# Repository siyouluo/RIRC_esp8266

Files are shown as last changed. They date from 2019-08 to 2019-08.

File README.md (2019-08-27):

# RIRC 红外遥控器

# 产品说明
本产品是一个空调遥控器，可以通过移动端APP进行远程控制。其硬件底层是通过模拟原装空调遥控器的红外波形，从而实现对特定型号空调的控制(暂仅支持格力空调YB0F2型号遥控器)。  
使用时需要将本产品连接到WiFi网络，手机需要安装对应APP并连网(数据网络或者WiFi)，手机**无需**和本产品处于同一局域网环境。  

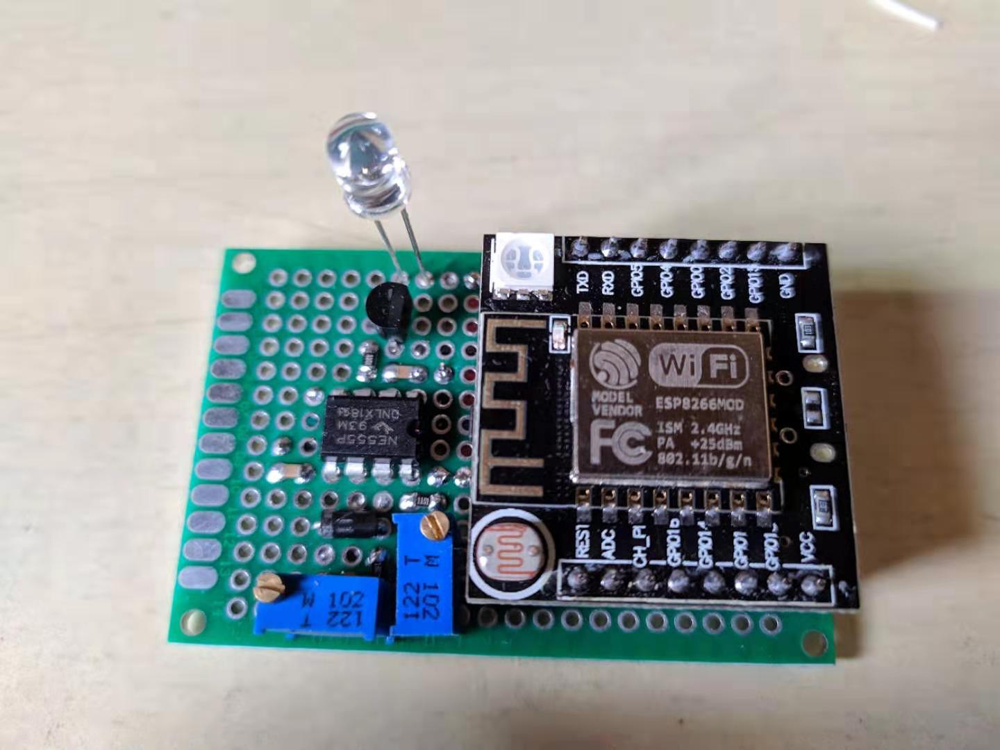
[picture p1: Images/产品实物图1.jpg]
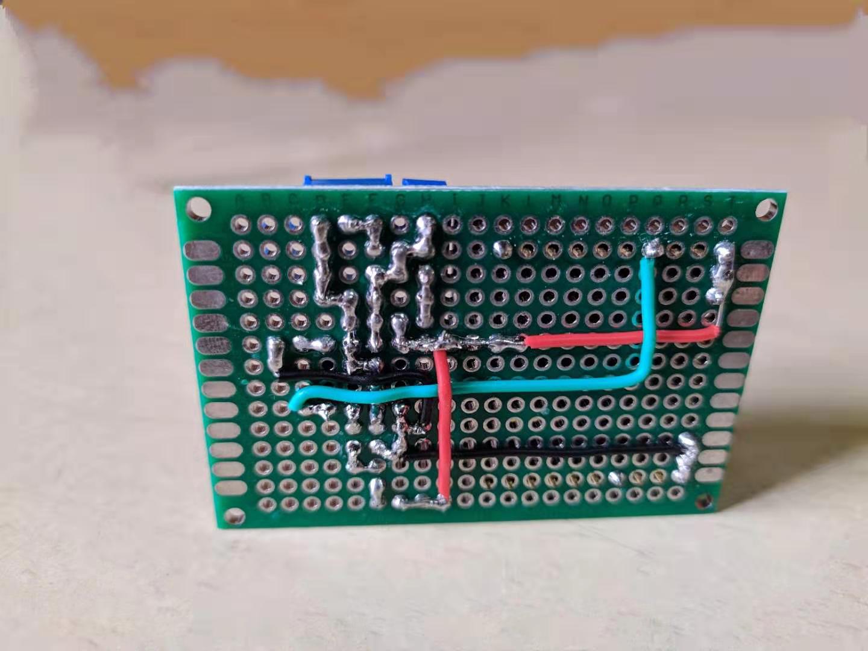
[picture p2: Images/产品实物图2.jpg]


本产品的主要使用场景有： 

1. 手机本身不包含红外发射装置，但又希望能直接通过手机控制空调;
2. 希望在户外提前打开空调，待用户到达房间时，温度已经调节合适;
3. 使用传感器获取当前时间、房间温度、光照强度等参数，并通过软件实现自动控制(暂未实现).

# 开发环境/辅助软件
Windows10 + VirtualBox虚拟机(lubuntu)

Multisim12.0 + Fritzing0.9.0b

# 器件清单
|元件|功能|图片|补充说明|参考价格|
|:---|:---|:---:|:---|:---|
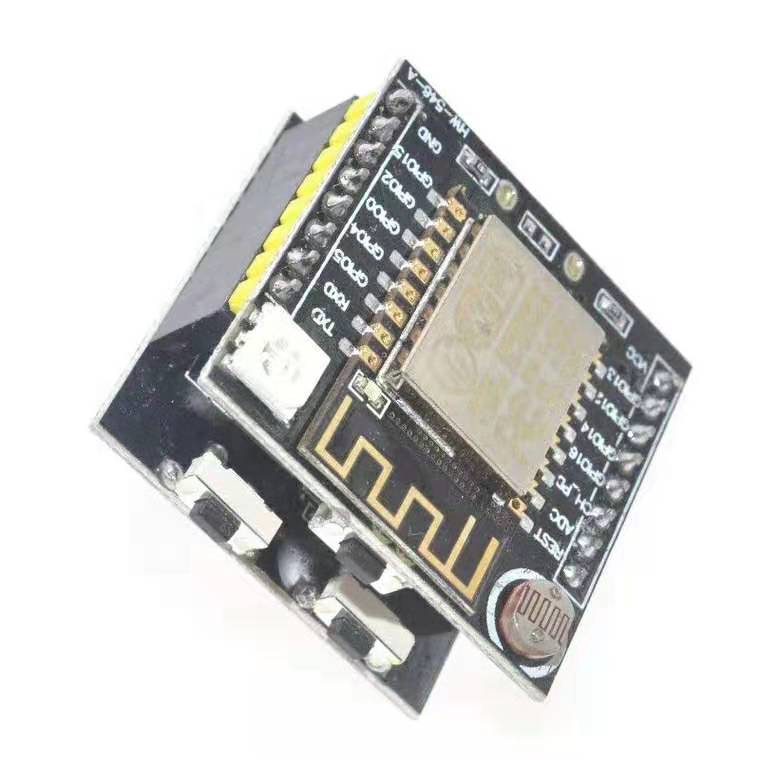
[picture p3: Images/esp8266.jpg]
|ESP8266-12F|WiFi模块||俗称“小黑板”|&yen;30.96| 
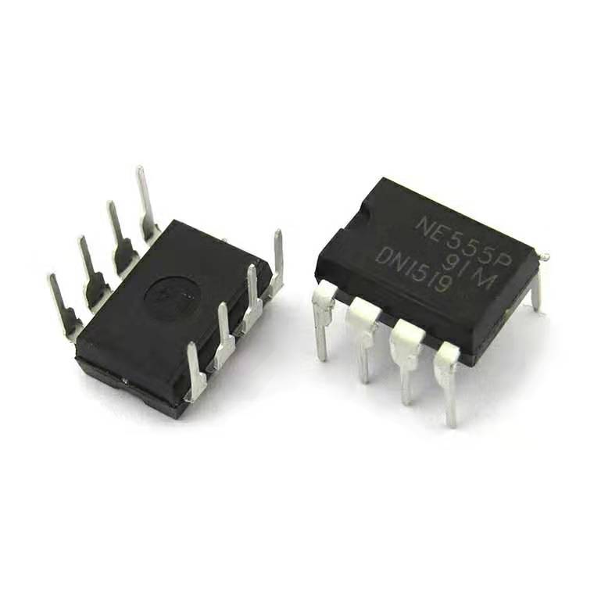
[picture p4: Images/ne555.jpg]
|NE555|定时器||DIP-8封装|&yen;3.6/10个|
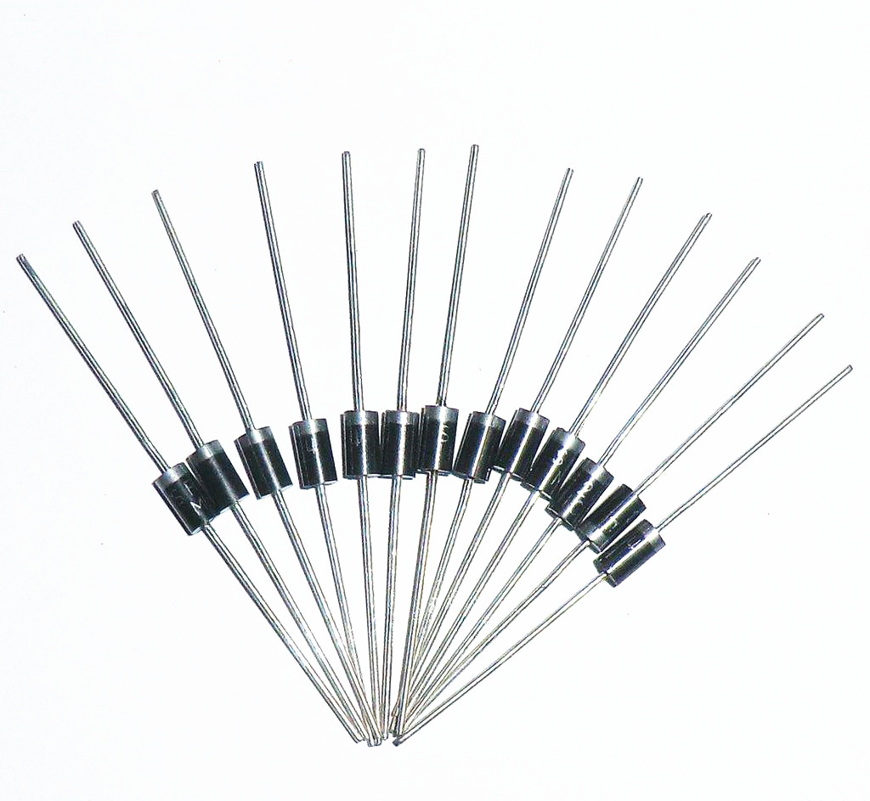
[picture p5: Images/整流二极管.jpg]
|整流二极管|振荡器辅助元件||便于调节占空比|&yen;5.5/100只|
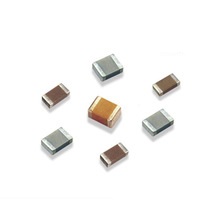
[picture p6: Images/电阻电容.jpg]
|电阻、电容|振荡器辅助元件||0805贴片封装|&yen;3.7/100个|  
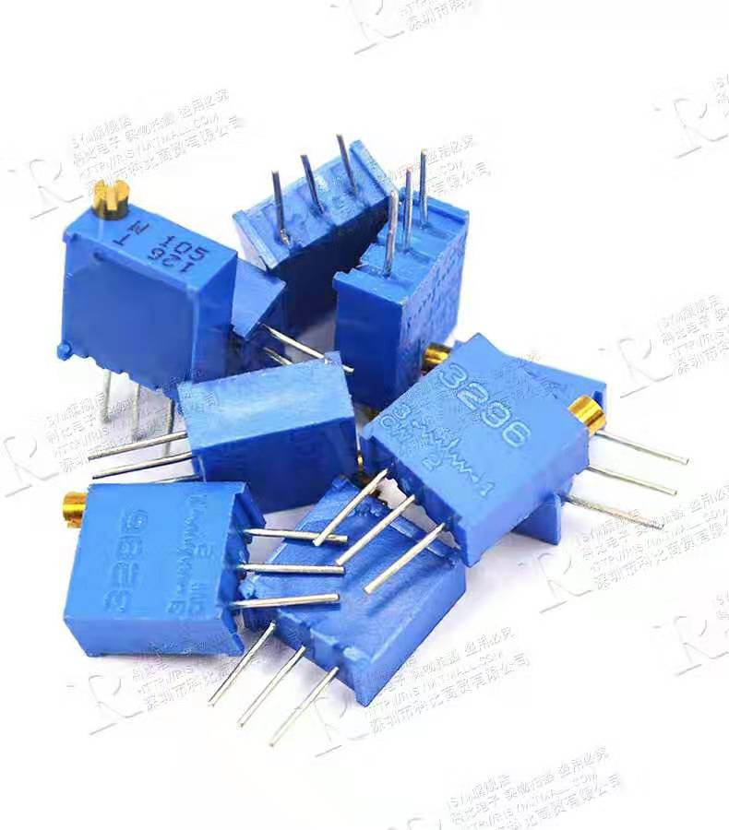
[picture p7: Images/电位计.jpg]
|多圈可调精密电位计|调节载波频率和占空比||3296W封装|&yen;2.31/5个|  
|NPN三极管|基本共射放大||9013|&yen;2.36/50个|  
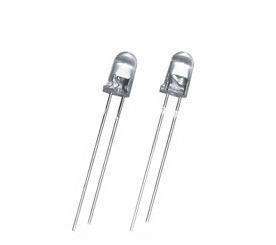
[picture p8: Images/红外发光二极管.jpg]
|红外发光二极管|发射红外光信号||5mm|&yen;2.08/10个|
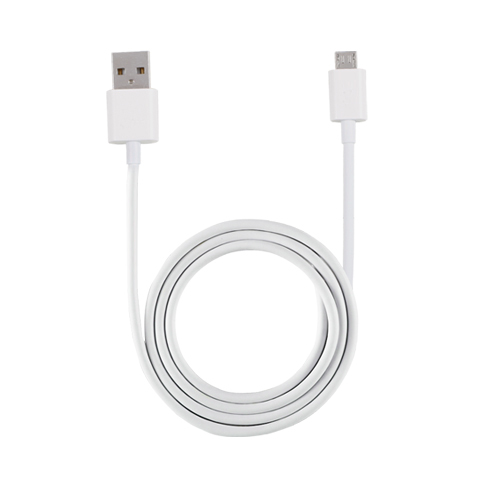
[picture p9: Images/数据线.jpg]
|数据线|供电||Micro-USB接口|&yen;10|
|洞洞板|电路载体|\*|7\*9cm|&yen;8.5/5片|  
|逻辑分析仪/示波器|辅助工具|\*|\*|\*|
|一体化红外接收头|辅助工具|\*|\*|\*|  

# 开发教程
如果你打算复现我的项目，可以参考以下文档：  
[格力空调红外协议](./Infrared_Protocol/readme.md)  
[红外信号载波](./Carrier_Wave/readme.md)  
[ESP8266开发教程](./ESP8266_Proj/readme.md)  

# 后续改进
1. 555定时器的方波不太稳有一个很高的尖峰脉冲，可以在3口加一个104的电解电容，或者用7555替代 [百度知道](https://zhidao.baidu.com/question/617617286604112012.html)
2. 载波产生电路中用了两个电位计来调载波频率和占空比，因为占空比是1/2，所以可以将频率调为76KHz，然后用D触发器二分频，得到占空比始终为1/2的载波，这样可以省去一个电位计，减少电位计阻值改变而引起载波变化，且易于调节

# 补充说明
本产品开发过程中参考了网络上其他开发者的教程，特此致谢！  
部分图片资料等来源于网络，如有侵权，请联系本人删除！

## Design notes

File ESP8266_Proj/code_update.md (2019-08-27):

# 代码修改
本文档主要解释自动生成的代码包需要如何修改  
直接从机智云开发者中心下载的自动生成代码包位于[./code_package/GizwitsSoCESP8266_32M20190826081308985208a7c6.zip](./code_package/)  
经过修改之后的代码位于[./code_package/SoC_ESP8266_32M_source.zip](./code_package/)  

# 点亮RGB LED  
在 app/driver/ 文件夹下添加C语言源文件，在 app/include/driver/ 文件夹下添加头文件，在 app/user/user_main.c 中初始化，在 app/Gizwits/gizwits_product.c 文件中添加业务逻辑  
参考[小黑板ESP8266无线wifi SoC方案连接机智云最详细图文教程](http://club.gizwits.com/forum.php?mod=viewthread&tid=5070&highlight=%E5%B0%8F%E9%BB%91%E6%9D%BF)  
## 添加驱动头文件
```diff
+++ app/include/driver/hal_led.h

#ifndef _HAL_RGB_LED_H
#define _HAL_RGB_LED_H

#include <stdio.h>
#include <c_types.h>
#include <gpio.h>
#include <eagle_soc.h>

/* Define your drive pin, when the io is low, the led will be lighted! */
#define GPIO_RGB_R	15
#define GPIO_RGB_G	12
#define GPIO_RGB_B	13

/* Set GPIO Direction */
#define RedOn()			GPIO_OUTPUT_SET(GPIO_ID_PIN(GPIO_RGB_R), 1)
#define RedOff()		GPIO_OUTPUT_SET(GPIO_ID_PIN(GPIO_RGB_R), 0)

#define GreenOn()		GPIO_OUTPUT_SET(GPIO_ID_PIN(GPIO_RGB_G), 1)
#define GreenOff()		GPIO_OUTPUT_SET(GPIO_ID_PIN(GPIO_RGB_G), 0)

#define BlueOn()		GPIO_OUTPUT_SET(GPIO_ID_PIN(GPIO_RGB_B), 1)
#define BlueOff()		GPIO_OUTPUT_SET(GPIO_ID_PIN(GPIO_RGB_B), 0)

/* Function declaration */
void rgbGpioInit(void);

#endif

```

## 添加驱动源文件

```diff
+++ app/driver/hal_led.c

/***********************************************
 * @file	hal_led.c
 * @author	Luo Siyou
 * @version	V1.0
 * @date	2019-07-26
 *
 * @brief	driver a gpio pin to simulate infrared protocol in order to control the airconditioner
 *
***********************************************/

#include "driver/hal_led.h"
#include "osapi.h"

void ICACHE_FLASH_ATTR rgbGpioInit(void)
{
	/* Migrate your driver code */
	PIN_FUNC_SELECT(PERIPHS_IO_MUX_MTDO_U, FUNC_GPIO15);
	PIN_FUNC_SELECT(PERIPHS_IO_MUX_MTDI_U, FUNC_GPIO12);
	PIN_FUNC_SELECT(PERIPHS_IO_MUX_MTCK_U, FUNC_GPIO13);

	gpio_output_set(0, 0, GPIO_ID_PIN(GPIO_RGB_R) |  GPIO_ID_PIN(GPIO_RGB_G) |  GPIO_ID_PIN(GPIO_RGB_B), 0);
	os_printf("rgbGpioInit \r\n");
	
	RedOff();
	GreenOff();
	BlueOff();
}

```

## 修改主程序

```diff  
--- app/user/user_main.c
+++ app/user/user_main.c 

#include "driver/hal_key.h"
+#include "driver/hal_led.h"

/**@name Key related definitions 
* @{
*/
-#define GPIO_KEY_NUM                            2                           ///< Defines the total number of key members
+#define GPIO_KEY_NUM                            1                           ///< Defines the total number of key members
-#define KEY_0_IO_MUX                            PERIPHS_IO_MUX_GPIO0_U      ///< ESP8266 GPIO function
+#define KEY_0_IO_MUX                            PERIPHS_IO_MUX_GPIO4_U      ///< ESP8266 GPIO function
-#define KEY_0_IO_NUM                            0                           ///< ESP8266 GPIO number
+#define KEY_0_IO_NUM                            4                           ///< ESP8266 GPIO number
-#define KEY_0_IO_FUNC                           FUNC_GPIO0                  ///< ESP8266 GPIO name
+#define KEY_0_IO_FUNC                           FUNC_GPIO4                  ///< ESP8266 GPIO name
-#define KEY_1_IO_MUX                            PERIPHS_IO_MUX_MTMS_U       ///< ESP8266 GPIO function
-#define KEY_1_IO_NUM                            14                          ///< ESP8266 GPIO number
-#define KEY_1_IO_FUNC                           FUNC_GPIO14                 ///< ESP8266 GPIO name
LOCAL key_typedef_t * singleKey[GPIO_KEY_NUM];                              ///< Defines a single key member array pointer
LOCAL keys_typedef_t keys;                                                  ///< Defines the overall key module structure pointer    

-/**
-* Key1 key short press processing
-* @param none
-* @return none
-*/
-LOCAL void ICACHE_FLASH_ATTR key1ShortPress(void)
-{
-    GIZWITS_LOG("#### KEY1 short press ,Production Mode\n");
-    
-    gizwitsSetMode(WIFI_PRODUCTION_TEST);
-}
-
-/**
-* Key1 key presses a long press
-* @param none
-* @return none
-*/
-LOCAL void ICACHE_FLASH_ATTR key1LongPress(void)
-{
-    GIZWITS_LOG("#### key1 long press, default setup\n");
-    
-    gizwitsSetMode(WIFI_RESET_MODE);
-}
-

/**
-* Key2 key to short press processing
+* key button short press processing
* @param none
* @return none
*/
-LOCAL void ICACHE_FLASH_ATTR key2ShortPress(void)
+LOCAL void ICACHE_FLASH_ATTR keyShortPress(void)
{
-    GIZWITS_LOG("#### key2 short press, soft ap mode \n");
+    GIZWITS_LOG("#### key short press, soft ap mode \n");

    gizwitsSetMode(WIFI_SOFTAP_MODE);
}

/**
-* Key2 button long press
+* Key button long press
* @param none
* @return none
*/
-LOCAL void ICACHE_FLASH_ATTR key2LongPress(void)
+LOCAL void ICACHE_FLASH_ATTR keyLongPress(void)
{
-    GIZWITS_LOG("#### key2 long press, airlink mode\n");
+    GIZWITS_LOG("#### key long press, airlink mode\n");    

    gizwitsSetMode(WIFI_AIRLINK_MODE);
}

/**
* Key to initialize
* @param none
* @return none
*/
LOCAL void ICACHE_FLASH_ATTR keyInit(void)
{
    singleKey[0] = keyInitOne(KEY_0_IO_NUM, KEY_0_IO_MUX, KEY_0_IO_FUNC,
-                                key1LongPress, key1ShortPress);
+                                keyLongPress, keyShortPress);

-    singleKey[1] = keyInitOne(KEY_1_IO_NUM, KEY_1_IO_MUX, KEY_1_IO_FUNC,
-                                key2LongPress, key2ShortPress);
    keys.singleKey = singleKey;
    keyParaInit(&keys);
}

...

+   //rgb led Init
+   rgbGpioInit();
    keyInit();

    gizwitsInit();  

    GIZWITS_LOG("--- system_free_size = %d ---\n", system_get_free_heap_size());
}

```

## 填充业务逻辑
根据数据点数据类型的不同，这部分代码可能不同，但不影响需要添加的部分。  
```diff
--- app/Gizwits/gizwits_product.c
+++ app/Gizwits/gizwits_product.c

#include "driver/hal_key.h"
+#include "driver/hal_led.h"

        switch(info->event[i])
        {
        case EVENT_On_Off :
            currentDataPoint.valueOn_Off = dataPointPtr->valueOn_Off;
            GIZWITS_LOG("Evt: EVENT_On_Off %d \n", currentDataPoint.valueOn_Off);
            if(0x01 == currentDataPoint.valueOn_Off)
            {
                //user handle
+		RedOn();
           }
            else
            {
                //user handle
+		RedOff();
           }
            break;
        case EVENT_Warm_Cold :
            currentDataPoint.valueWarm_Cold = dataPointPtr->valueWarm_Cold;
            GIZWITS_LOG("Evt: EVENT_Warm_Cold %d \n", currentDataPoint.valueWarm_Cold);
            if(0x01 == currentDataPoint.valueWarm_Cold)
            {
                //user handle
+		GreenOn();
            }
            else
            {
                //user handle
+		GreenOff();
            }
            break;

        case EVENT_Temperature:
            currentDataPoint.valueTemperature= dataPointPtr->valueTemperature;
            GIZWITS_LOG("Evt:EVENT_Temperature %d\n",currentDataPoint.valueTemperature);
            //user handle
+            if(currentDataPoint.valueTemperature>25)
+            {
+                BlueOn();
+            }
+            else
+            {
+                BlueOff();
+            }
            break;

...
            
        default:
            break;
        }

```

# 模拟NEC协议
ESP8266的管脚上只需要产生基带信号，然后接到555定时器的RST管脚进行调制，555定时器输出已调信号，因为RST无效时，555定时器输出恒定低电平，所以当三极管基极为低电平时需要截止，所以三极管选用NPN管，基本共射放大接法。

接下来我直接列出需要修改或添加的文件，你可以直接使用我的代码文件：  

## 添加文件  
app/include/driver/hal_led.h  
app/driver/hal_led.c  
app/include/driver/hal_ir.h  
app/driver/hal_ir.c  

## 替换文件
将以下文件用我的对应文件进行替换  
app/user/user_main.c  
app/Gizwits/gizwits_product.c

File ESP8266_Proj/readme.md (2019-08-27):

# ESP8266 PROJECT

# 开发流程

## 注册开发者账号
访问[机智云开发者中心](https://dev.gizwits.com/zh-cn/developer/)，注册开发者账号并登录  
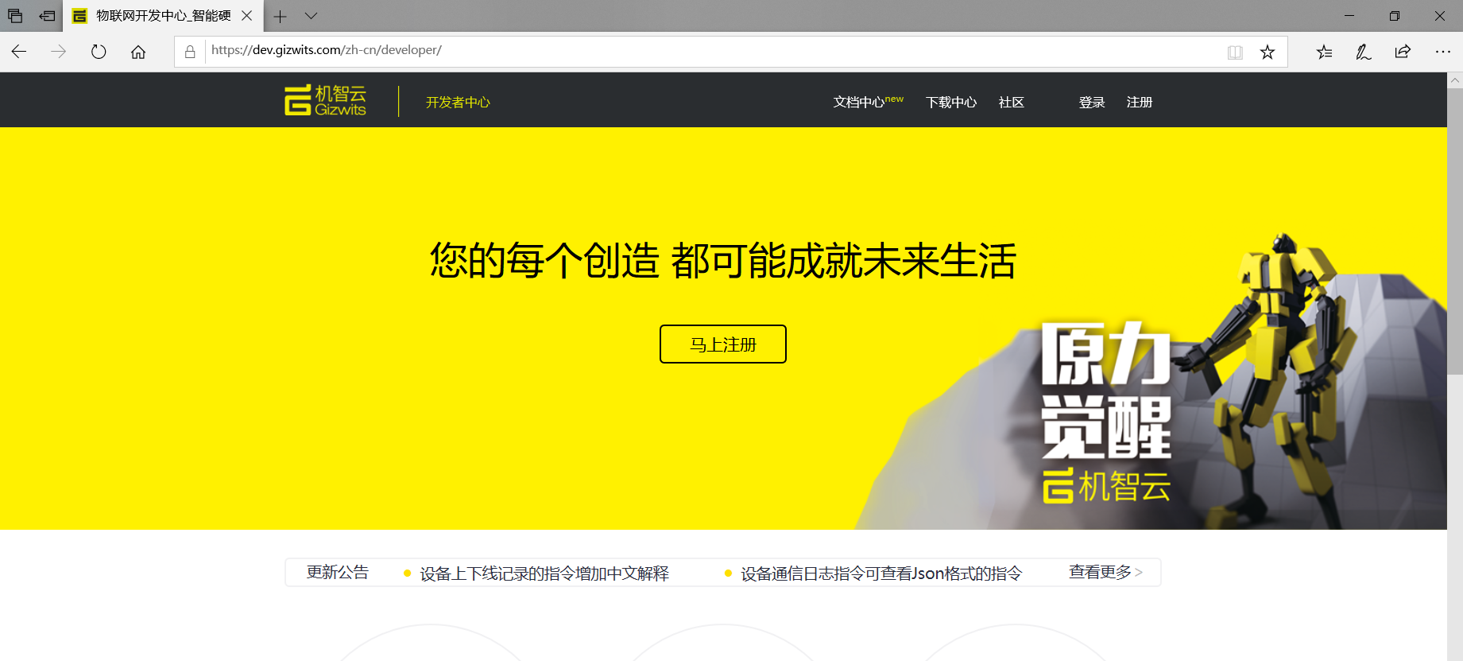
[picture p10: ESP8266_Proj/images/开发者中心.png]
  

## 创建产品
创建新产品，选择产品分类、名称、技术方案等  
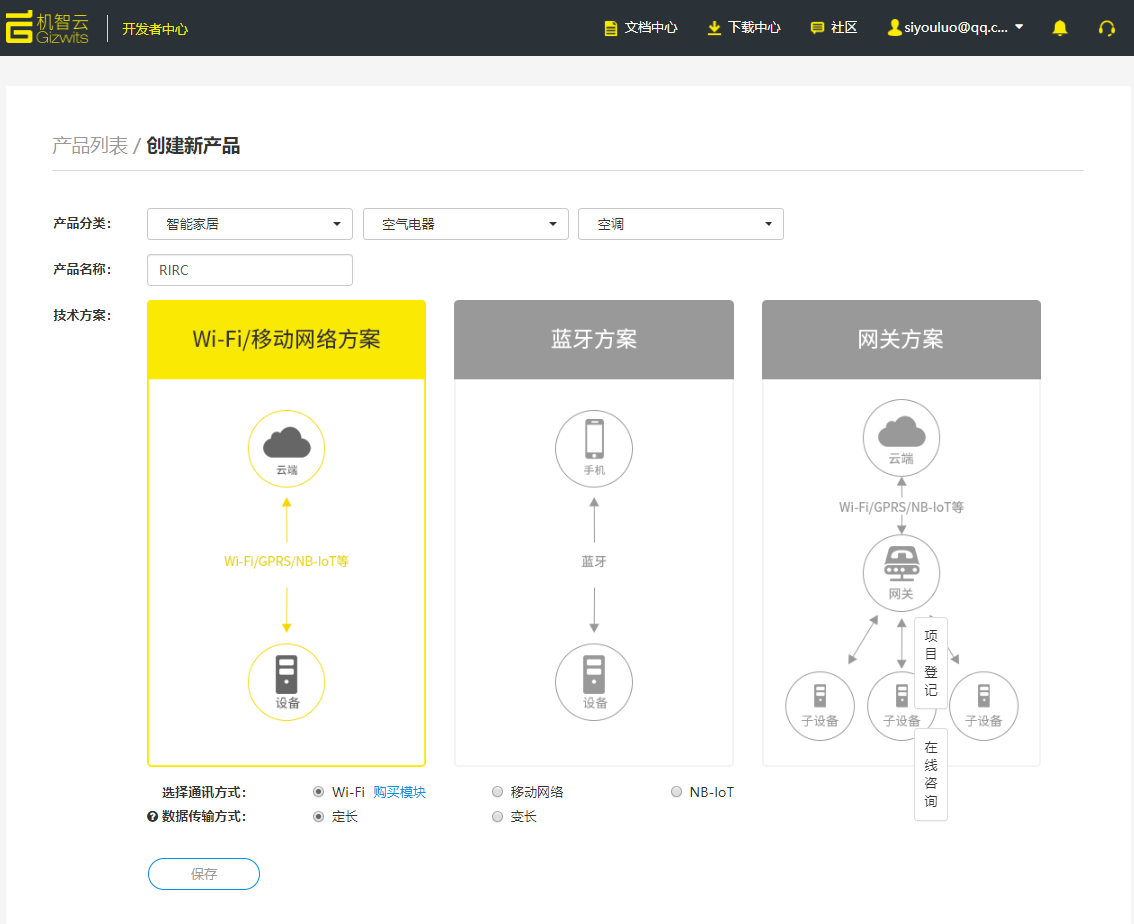
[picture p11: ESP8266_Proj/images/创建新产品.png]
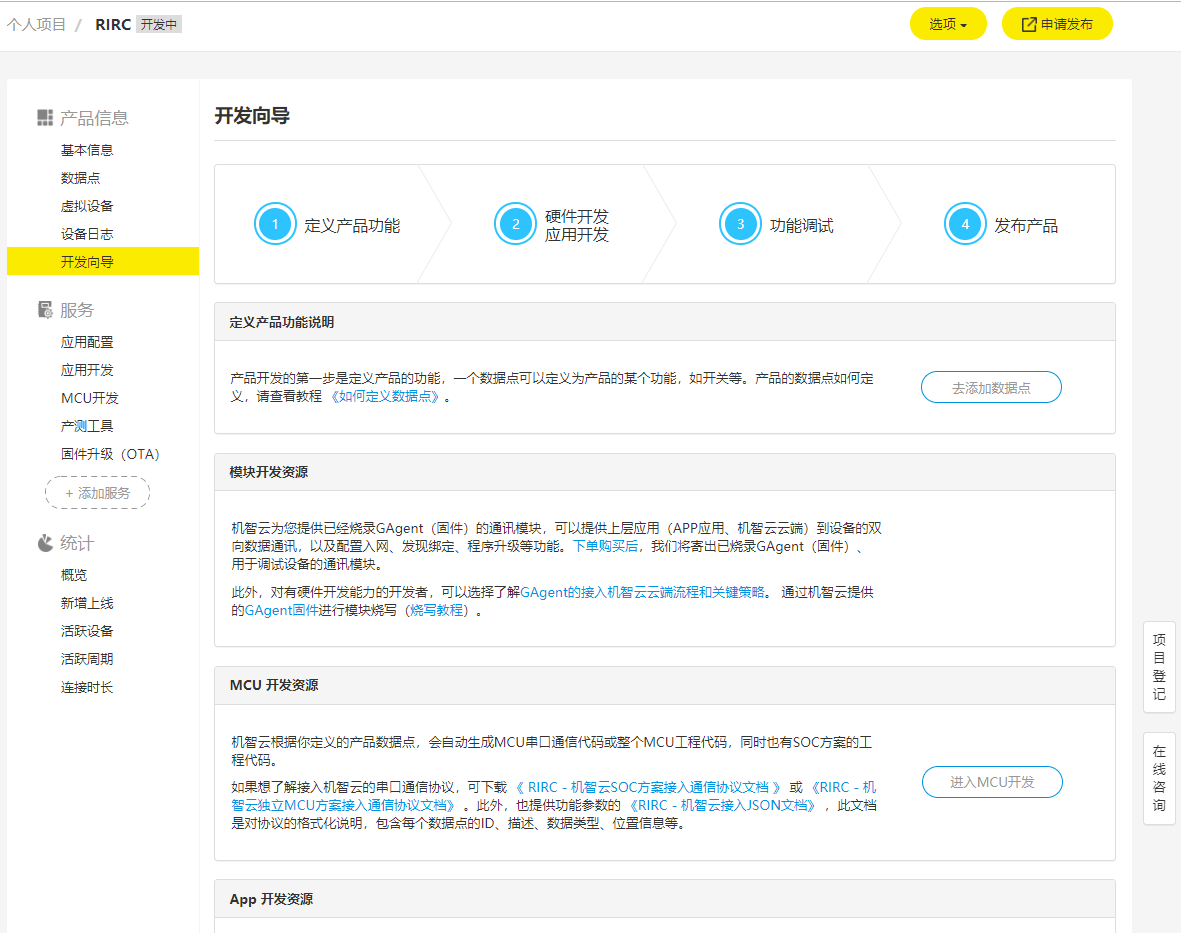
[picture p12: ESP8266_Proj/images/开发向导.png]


## 添加数据点
> 数据点是一套机智云设备通信协议，用于描述设备功能及其参数  

[如何定义数据点-官方教程](http://docs.gizwits.com/zh-cn/quickstart/datapoint_tutorial.html)  
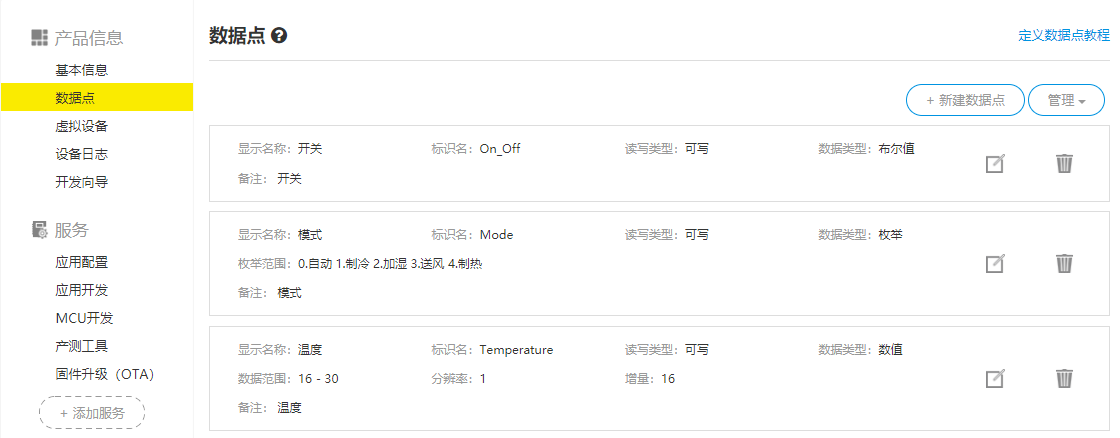
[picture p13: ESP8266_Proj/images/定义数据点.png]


*我一共添加了3个数据点，开关-布尔值，模式-枚举，温度-数值。这是最新版的数据点及其数据类型，本文档其他部分可能显示其他数据类型，请以上图为准。*  
*关于枚举：如果某个数据点是枚举类型，且当前值为枚举值1，这时在APP上点击枚举值1，将不会触发事件服务程序，只有点击与当前值不同的值时才会有响应。*

## 虚拟设备
> 通过虚拟设备模拟真实设备上报数据的行为，可以快速验证接口功能的开发。
> 用您开发的app或 下载Demo App 绑定虚拟设备，即可对虚拟设备进行远程控制及查看通讯日志。

下载[demo App](https://download.gizwits.com/zh-cn/p/98/99), 点击启动虚拟设备，点击显示二维码，在demo App上扫描虚拟设备二维码，绑定虚拟设备。在App上就可以更改数据点的值(限于可写类型的数据点)，这时在网页上可以看到相应的改变。对于只读类型的数据点，只可以在网页上更新数据点的值，并模拟设备上报(点击推送)，这时在APP上可以看到相应的改变。  
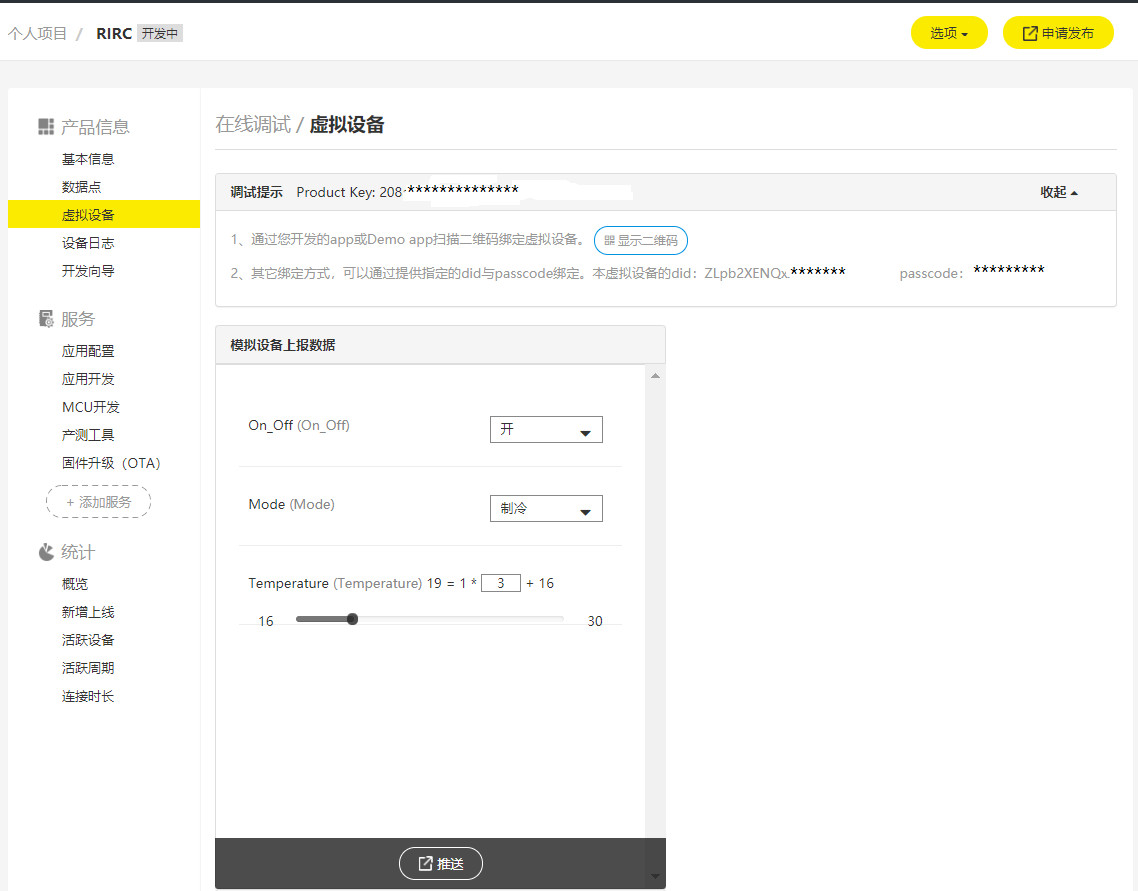
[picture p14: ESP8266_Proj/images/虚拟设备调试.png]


## MCU开发(SOC方案)  
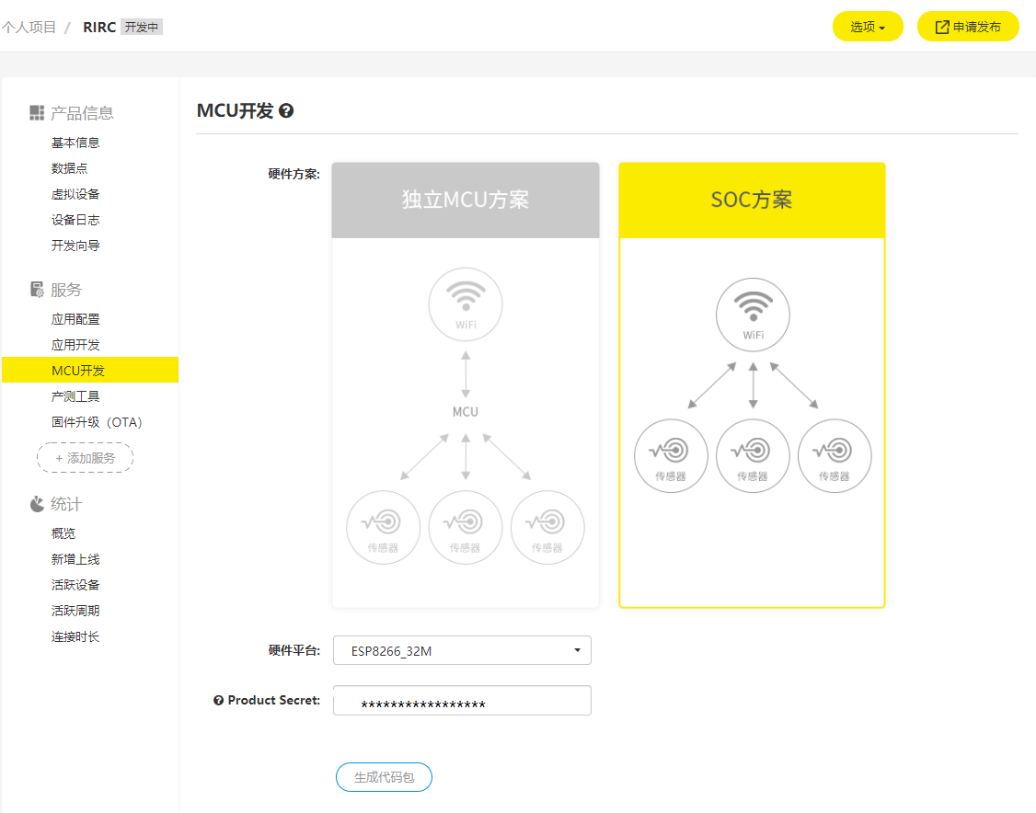
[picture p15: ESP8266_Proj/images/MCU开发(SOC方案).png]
    
Product secret可以在产品信息中查看，点击生成代码包，并下载  

*修改数据点之后需要点击“修改”，重新生成代码包并下载*  

我的代码已下载到 
[code_package](./code_package)文件夹下

## 固件开发
参考论坛帖子[GoKit3(S) 二次开发--开发环境搭建](http://docs.gizwits.com/zh-cn/deviceDev/WiFiSOC/GoKit3S%E4%BA%8C%E6%AC%A1%E5%BC%80%E5%8F%91.html)配置编译环境(virtural box + lubuntu)  
将代码包解压后剪切到share文件夹下
在virtual box中运行./mount.sh之后可以在Share文件夹下看到我们的代码包(第一次需要输入用户密码： “espressif”，回车确认)

直接使用自动生成的代码包也可以编译，我们可以按照上面帖子进行编译。  
有时候会出现下面这个警告，重新编译一下就好了。
```bash
make: warning:  Clock skew detected.  Your build may be incomplete.
```

编译生成的固件位于~/Share/SoC_ESP8266_32M_source/bin/upgrade/文件夹下,在windows系统中也可见  
此时编译得到的固件还是原始固件，并没有进行二次开发，也就是说还没有添加业务逻辑  
为了简便起见，我们先不去控制红外二极管，而是先参考论坛帖子[小黑板ESP8266无线wifi SoC方案连接机智云最详细图文教程](http://club.gizwits.com/forum.php?mod=viewthread&tid=5070&highlight=%E5%B0%8F%E9%BB%91%E6%9D%BF)点亮板载的一颗RGB LED灯

代码完成后重新编译即可，详细的代码解释参考[code_update](./code_update.md)  

## 固件下载
到乐鑫官网下载[固件下载工具](https://www.espressif.com/zh-hans/support/download/other-tools)选择Flash 下载工具（ESP8266 & ESP32）  
你也可以使用我下载的软件：[flash_download_tools_v3.6.6](../Tools/flash_download_tools_v3.6.6/)  
双击 flash_download_tools_v3.6.6.exe 文件，选择ESP8266 DownloadTool，并按照代码包中的 32M固件烧录说明.jpg 进行烧录

烧录时，将“小黑板”两块对接，用USB数据线连接电脑和底板(带有两个按键)的Micro-USB接口，点击下载。完成后点击RST键复位开始运行。

## 配置入网
手机安装demo App,连接WiFi(2.4GHz)  
长按(3s以上)WiFi模块上的按键，进入airlink模式，打开demoApp，点击“+”，一键配置，选择WiFi网络，输入密码，选择乐鑫，点击“我已完成上述操作”，开始搜索小黑板，……


## 固件升级(OTA)

第一次下载固件时，需要将ESP8266连接到USB转TTL模块上，再连接到电脑下载4个文件（参考[固件下载](#固件下载)），当设备已经部署完成后，可能无法将ESP8266取下，不方便通过有线方式刷写固件，或者开发者不在设备部署现场，无法亲自操作。  
这时候就可以使用OTA方式升级固件，你可以按照[OTA固件升级-官方教程](http://docs.gizwits.com/zh-cn/deviceDev/WiFiSOC/GoKit3S%E4%BA%8C%E6%AC%A1%E5%BC%80%E5%8F%91.html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)进行操作，OTA升级固件时只需要下载bin/upgrade/*.bin一个文件即可。  
*有时可能固件下载完成后，报错：固件验证失败。可能其实是验证成功，ESP8266设备重启即可工作。*  

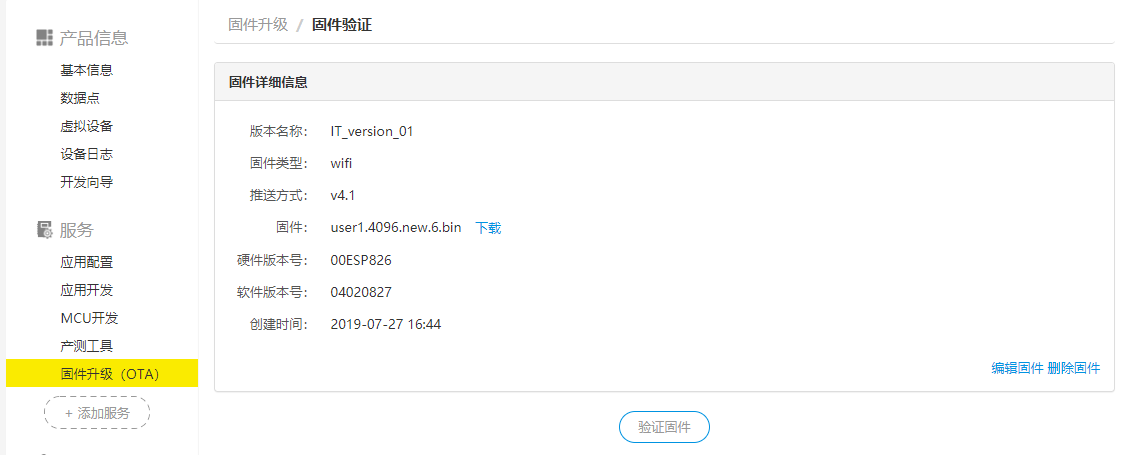
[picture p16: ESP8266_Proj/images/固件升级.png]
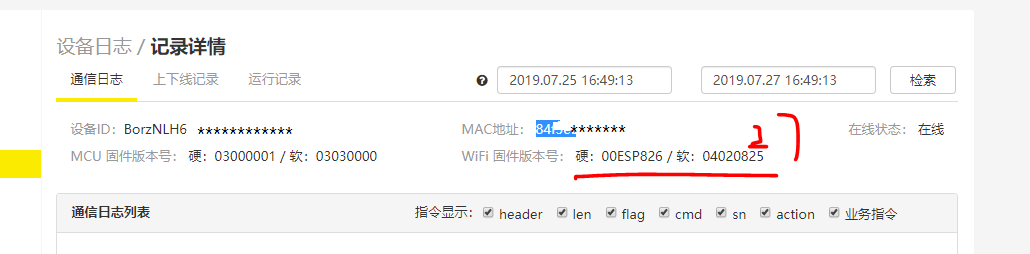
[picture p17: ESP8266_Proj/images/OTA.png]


# 友情链接
[机智云-官网](http://www.gizwits.com/)  
[机智云开发者中心](https://dev.gizwits.com/zh-cn/developer/)  
[机智云论坛](http://club.gizwits.com/forum.php)  
[小黑板ESP8266无线wifi SoC方案连接机智云最详细图文教程](http://club.gizwits.com/forum.php?mod=viewthread&tid=5070&highlight=%E5%B0%8F%E9%BB%91%E6%9D%BF)  
[小黑板 ESP8266无线wifi SoC方案连接机智云最详细图文教程2](http://club.gizwits.com/forum.php?mod=viewthread&tid=5176&highlight=%E5%B0%8F%E9%BB%91%E6%9D%BF)  
[小黑板 ESP8266无线wifi SoC方案连接机智云最详细图文教程3](http://club.gizwits.com/forum.php?mod=viewthread&tid=5453&highlight=%E5%B0%8F%E9%BB%91%E6%9D%BF)  
[GoKit3(S) 二次开发--开发环境搭建](http://docs.gizwits.com/zh-cn/deviceDev/WiFiSOC/GoKit3S%E4%BA%8C%E6%AC%A1%E5%BC%80%E5%8F%91.html)

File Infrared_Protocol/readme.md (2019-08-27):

# 红外编码协议
本项目暂时只研究了格力空调遥控器(YBOF2)的编码协议，其他型号空调及遥控器可能不同，可能需要另行分析。

# 分析方式
为了准确模拟所使用空调遥控器的红外编码，需要通过实验进行验证。  
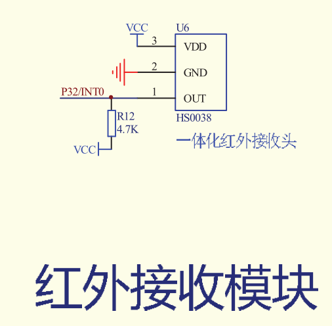
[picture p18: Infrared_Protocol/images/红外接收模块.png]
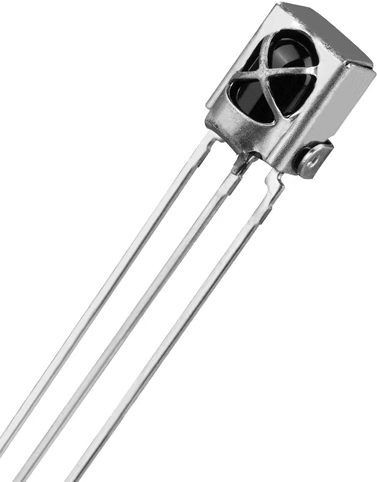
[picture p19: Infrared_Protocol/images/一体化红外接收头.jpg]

使用如上图所示电路接收空调原装遥控器的红外信号，其中一体化红外接收头的OUT管脚通过上拉电阻接到5V电平。
接收到红外信号时，OUT管脚被拉低；否则上拉为高电平。
需注意，经过接收头接收之后已去除载波，但自己设计红外发射电路时，必须加上38KHz载波，否则接收头无法接收到红外信号。  
&nbsp;
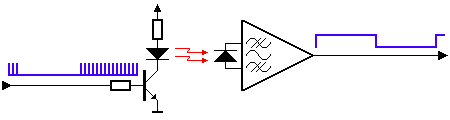
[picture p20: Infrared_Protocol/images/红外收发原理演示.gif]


# 协议解析
经过试验观测，格力空调红外遥控器YB0F2所发射的红外信号波形如下图  
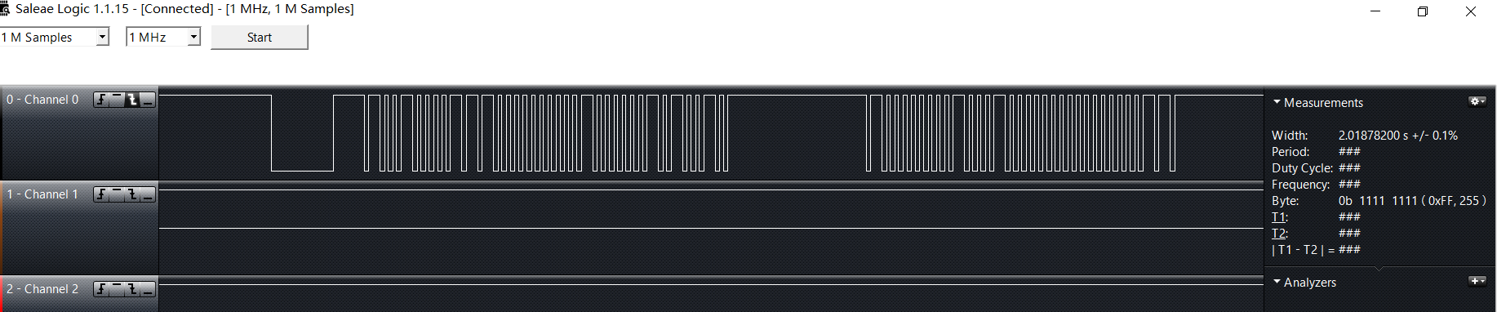
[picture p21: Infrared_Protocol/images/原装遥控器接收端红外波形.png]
  
图中可以看出，该红外信号主要包括4个部分： 

1. 起始码(S):   9000us低电平 + 4500us高电平
2. 35bit数据码
3. 连接码(C):   600us低电平 +20000us高电平
4. 32bit数据码  

其中数据码电平格式为：  
0:  600us低电平 + 600us高电平  
1:  600us低电平 + 1600us高电平  

前35bit数据码：  

<div align="center">
<table border="1" cellspacing="0" cellpadding="0" width="100%">
<tr style="background:#C0C0C0;" align="center">
<td>1</td>
<td>2</td>
<td>3</td>
<td>4</td>
<td>5</td>
<td>6</td>
<td>7</td>
<td>8</td>
<td>9</td>
<td>10</td>
<td>11</td>
<td>12</td>
<td>13</td>
<td>14</td>
<td>15</td>
<td>16</td>
</tr>

<tr style="background:#C0CFC0;" align="center">
<td>1</td>
<td>0</td>
<td>0</td>
<td>1</td>
<td>0</td>
<td>0</td>
<td>1</td>
<td>0</td>
<td>1</td>
<td>1</td>
<td>1</td>
<td>0</td>
<td>0</td>
<td>0</td>
<td>0</td>
<td>0</td>
</tr>

<tr style="background:#FFFFFF;" align="center">
<td width="18.75%" colspan="3">模式标志</td>
<td width="6.25%">开关</td>
<td width="12.5%" colspan="2">风速</td>
<td width="7.25%">扫风</td>
<td width="6.25%">睡眠</td>
<td width="23%" colspan="4">温度数据</td>
<td width="25%" colspan="4">定时数据</td>
</tr>

<tr style="background:#C0C0C0;" align="center">
<td>17</td>
<td>18</td>
<td>19</td>
<td>20</td>
<td>21</td>
<td>22</td>
<td>23</td>
<td>24</td>
<td>25</td>
<td>26</td>
<td>27</td>
<td>28</td>
<td>29</td>
<td>30</td>
<td>31</td>
<td>32</td>
</tr>

<tr style="background:#C0CFC0;" align="center">
<td>0</td>
<td>0</td>
<td>0</td>
<td>0</td>
<td>0</td>
<td>1</td>
<td>0</td>
<td>0</td>
<td>0</td>
<td>0</td>
<td>0</td>
<td>0</td>
<td>1</td>
<td>0</td>
<td>1</td>
<td>0</td>
</tr>

<tr style="background:#FFFFFF;" align="center">
<td colspan="4">定时数据</td>
<td>加湿</td>
<td>灯光</td>
<td>负离子</td>
<td>节电</td>
<td>换气</td>
<td colspan="7">所有按键均显示此值</td>
</tr>

<tr style="background:#C0C0C0;">
<td>33</td>
<td>34</td>
<td>35</td>
<td width="76%" colspan="13"> </td>
</tr>

<tr style="background:#C0CFC0;">
<td>0</td>
<td>1</td>
<td>0</td>
<td width="76%" colspan="13"></td>
</tr>

<tr style="background:#FFFFFF;">
<td width="23%" colspan="3">所有按键均显示此值</td>
<td width="76%" colspan="13"></td>
</tr>

</table>
</div>

后32bit数据码：  

<div align="center">
<table border="1" cellspacing="0" cellpadding="0" width="100%">
<tr style="background:#C0C0C0;" align="center">
<td>36</td>
<td>37</td>
<td>38</td>
<td>39</td>
<td>40</td>
<td>41</td>
<td>42</td>
<td>43</td>
<td>44</td>
<td>45</td>
<td>46</td>
<td>47</td>
<td>48</td>
<td>49</td>
<td>50</td>
<td>51</td>
</tr>

<tr style="background:#C0CFC0;" align="center">
<td>1</td>
<td>0</td>
<td>0</td>
<td>0</td>
<td>1</td>
<td>0</td>
<td>0</td>
<td>0</td>
<td>0</td>
<td>1</td>
<td>0</td>
<td>0</td>
<td>0</td>
<td>1</td>
<td>0</td>
<td>0</td>
</tr>

<tr style="background:#FFFFFF;" align="center">
<td>上下扫风</td>
<td colspan="3"></td>
<td>左右扫风</td>
<td colspan="3"></td>
<td colspan="2">温度显示</td>
<td colspan="6">所有按键均显示此值</td>
</tr>

<tr style="background:#C0C0C0;" align="center">
<td>52</td>
<td>53</td>
<td>54</td>
<td>55</td>
<td>56</td>
<td>57</td>
<td>58</td>
<td>59</td>
<td>60</td>
<td>61</td>
<td>62</td>
<td>63</td>
<td>64</td>
<td>65</td>
<td>66</td>
<td>67</td>
</tr>

<tr style="background:#C0CFC0;" align="center">
<td>0</td>
<td>0</td>
<td>0</td>
<td>0</td>
<td>0</td>
<td>0</td>
<td>0</td>
<td>0</td>
<td>0</td>
<td>0</td>
<td>0</td>
<td>0</td>
<td>1</td>
<td>0</td>
<td>1</td>
<td>1</td>
</tr>

<tr style="background:#FFFFFF;" align="center">
<td colspan="10">所有按键均显示此值</td>
<td>节能</td>
<td></td>
<td colspan="4">校验码</td>
</tr>

</table>
</div>

上表中，大于两位的数据都采取“小端法”，低位在低地址（左），各数据的意义如下：  

|模式标志|自动|制冷|加湿|送风|制热|
|---|---|---|---|---|---|
|数据码|000|100|010|110|001|

|风速标志|自动|一级|二级|三级|
|---|---|---|---|---|
|数据码|00|10|01|11|

|温度|16度|17度|18~29度|30度|
|---|---|---|:---:|---|
|数据码|0000|1000|~|0111|

后32bit数据码中最后4bit为校验码，似乎不同型号的遥控器校验码不同，经过测试，我所使用的遥控器校验规则如下：  
```c
//校验码
void checkout()
{
	unsigned char check;
	check = IR_CodeBuf[1] + IR_CodeBuf[2]*2 + IR_CodeBuf[3]*4+IR_CodeBuf[4]*8;//模式
	check += IR_CodeBuf[9] + IR_CodeBuf[10]*2 + IR_CodeBuf[11]*4 + IR_CodeBuf[12]*8;//温度
	check += IR_CodeBuf[25];//换气
	check += IR_CodeBuf[40];//左右扫风
	check += IR_CodeBuf[62];//节能
	check += 12;
	check &= 0x0f;

	IR_CodeBuf[64] = check&1;
	IR_CodeBuf[65] = (check>>1)&1;
	IR_CodeBuf[66] = (check>>2)&1;
	IR_CodeBuf[67] = (check>>3)&1;
}

```
*这里稍微注意一下，我声明的协议码是68个元素的数组，实际上只用得到 1~67，其中IR_CodeBuf[0]没用，这是为了和我参考的一个博客上的下标相兼容*

# 软件模拟
*这一部分是之前用51单片机完成的，载波通过MCU内部定时器产生*  
通过软件模拟控制I/O口时序，并用逻辑分析仪检测波形  
将遥控器温度调为23度，发射红外光分析数据码，将此数据码作为软件模拟的初始化数据  
前35位数据码：1001 0010 1110 0000 0000 0100 0000 1010 010  
后32位数据码：1000 1000 0100 0100 0000 0000 0000 1011  
其中：  
Channel 1是sbit IR_LED=P2^4模拟的波形  
Chennel 0是一体化红外接收头接收到的波形  
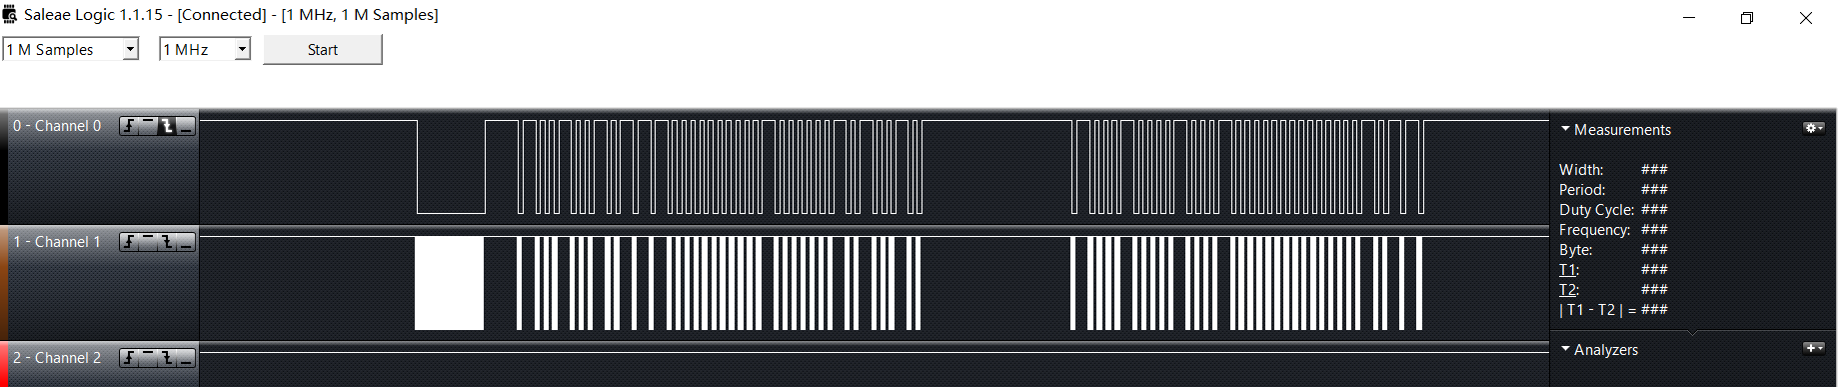
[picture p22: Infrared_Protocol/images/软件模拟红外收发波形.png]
  
局部放大：  
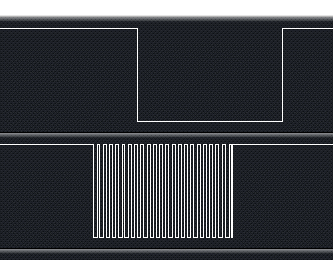
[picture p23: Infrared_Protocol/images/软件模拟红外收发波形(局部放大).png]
  

# 友情链接
[格力空调遥控器红外编码透析（长码） - CSDN博客](https://blog.csdn.net/yannanxiu/article/details/48174649)  
[红外遥控一体化接收头原理及应用1](http://www.360doc.com/content/14/0620/10/1437142_388278585.shtml)

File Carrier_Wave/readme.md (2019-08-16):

# 载波
基带信号具有较低的频率分量，只有经过高频载波的调制之后，才能通过无线信道进行传输。  
格力空调YB0F2型号遥控器使用的载波频率是38KHz，占空比1/2. 即载波高电平时间和低电平时间都是13.16us，允许略微偏差。  

## 载波发生方式
1. 据说esp8266的GPIO14管脚可以产生标准的38KHz，占空比1/2的载波，我之前尝试过，效果不好，空调无法识别，也许是我某个地方没有配置好，这个方案保留。  
2. 我使用的第二个方案是将控制命令从esp8266通过串口发送给其他的单片机，利用单片机的高精度定时器资源产生载波，这个方案完全可行，但是esp8266作为一个SoC，本身就是一块处理器，这样未免累赘。且进行系统升级时，需要同时修改esp8266和单片机的固件，比较麻烦。  
3. 因此我现在选择使用硬件方式产生载波，用一个555定时器，外接电阻、电容产生38KHz方波信号，555芯片有一个RST引脚。RST接高电平时，输出方波；接地时输出低电平，这样就实现了调制。  

## 555定时器原理图
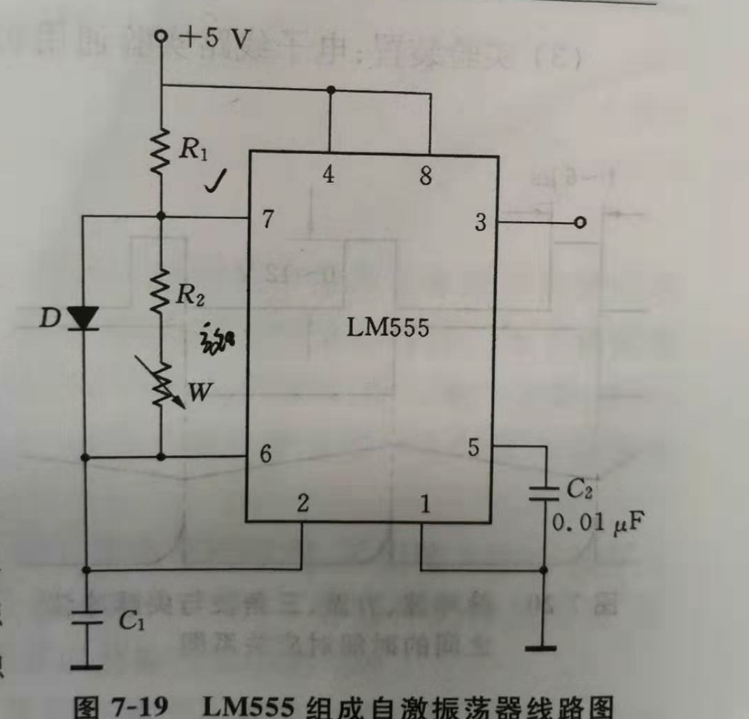
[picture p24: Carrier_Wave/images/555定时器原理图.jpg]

注意上图中二极管D的作用十分重要，如果不接这个二极管，那么振荡器输出高电平的时间与R1+R2有关，低电平时间与R2有关。这样在调节电位计W时会同时改变振荡器输出频率与占空比。接入二极管之后，

**高电平时间**:	$t_1 = 0.693R_1C_1$  
**低电平时间**:	$t_2 = 0.693(R_2+W)C_1$  

这样，可以方便地调节占空比和周期。经过测试，R1=1.1K,R2=1.8K时可以产生所需要的载波，因此，将原理图中R1用510欧姆定值电阻和1K精密电位计替换，R2用1.3K定值电阻，W用1K精密电位计，C1取0.01uF.  
*这里两个电阻和电位计的取值可能需要你用面包板搭个电路进行测试，然后用示波器或者逻辑分析仪观测，不断尝试以得出电阻的合适取值，似乎不同的芯片略有区别，实际电路和Multisim仿真也略有区别*

*有的地方会说格力空调占空比为1/3，可能指的是调制占空比，即传送符号"1"时，脉冲持续时间(560us)占低电平时间(1680us)的1/3；  
也有的地方提到说“NEC协议载波占空比推荐为1/3或1/4”，但是格力空调使用的并不是标准的NEC协议。*

# 友情链接
[红外线发射的最佳占空比-百度知道提问](https://zhidao.baidu.com/question/469841290.html)  
[利用555定时器实现38KHZ方波的输出](https://blog.csdn.net/nausicaaaa/article/details/5597119)  
[Fritzing电路图](../Fritzing_Proj/)  
[Multisim12.0仿真](../Multisim_Proj/)

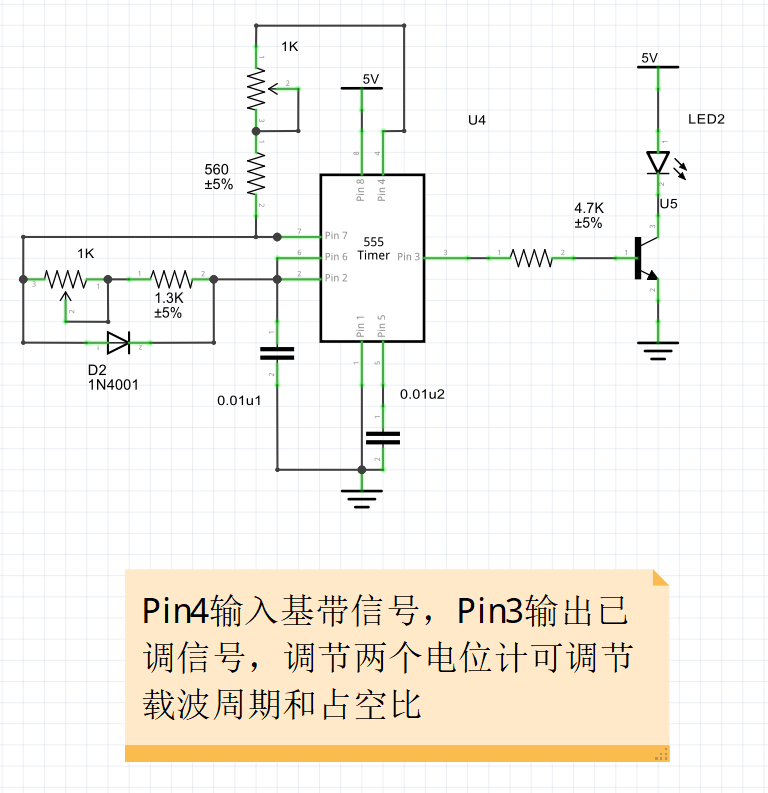
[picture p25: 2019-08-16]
Fritzing_Proj/images/schematic.png

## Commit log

2019-08-16 V2.0 initial commit
    [ESP32_RF_INIT.xlsx, ESP8266_Pin_List.xls, ESP8266_RF_init.xls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]
2019-08-27 完善部分文档
